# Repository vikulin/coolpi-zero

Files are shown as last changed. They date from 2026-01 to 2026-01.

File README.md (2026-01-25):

# GammaPi Zero - The portable FPGA development board



## What is the GammaPi Zero?

The GammaPi Zero is an FPGA development board in the popular Raspberry Pi Zero form factor inheriting Icepi Zero board. It carries a Lattice ECP5 25F, enabling powerful designs while keeping a small portable size. It also has a GPDI mini (General Purpose Display Interface, same as the one on the Pi Zero) port allowing easy digital video output.



## Why GammaPi Zero?

Currently most powerful FPGA boards on the market are expensive and bulky.

I've always wanted a low-cost portable FPGA with video output to make my own CPU, but there isn't any on the market.

The GammaPi Zero aims to fix this. Carrying a powerful ECP5 FPGA on a small Raspberry Pi Zero form factor, it is the ultimate portable solution for FPGA development. Additionally packing a GPDI mini port and 3 USB-C ports, it allows interfacing with multiple external I/O devGammas.

GammaPi Zero is for everyone: Students can use it to learn about the internals of modern processors. Gamers can use it to emulate old hardware. Programmers can use it to test their code on multiple architectures.


<sub>Oberon running on GammaPi Zero</sub>

GammaPi Zero also has an on-board USB to JTAG converter, so no external programmers are needed.

Moreover GammaPi Zero is fully open-source, no strings attached. Learn from the design! ([OSHWA cerified FR000026](https://certification.oshwa.org/fr000026.html)).



## Features
    * Lattice ECP5U-25F-CABGA256 FPGA
    * 256 Mib SDRAM
    * DVI video output via HDMI connector
    * 25 MBPS ADC
    * 3× USB ports (1× programming/JTAG, 2× general purpose)
    * USB-JTAG programming interface
    * Mini SD card reader
    * 5× RGB LEDs
    * 2× user buttons
    * RP Zero–compatible pins and board size
    * Board dimensions: 65 × 30 mm

This powerful configuration allows the PCB to be used in numerous ways, including real time video processing, hardware AI acceleration and prototyping of ASICs. 

## Emulation

Over the course of multiple weeks, multiple emulation cores have been ported over, such as the [Oberon](https://github.com/cheyao/oberon), [Apple I](https://github.com/cheyao/apple-one) and the [Acorn Atom](https://github.com/cheyao/acorn_atom)! The GammaPi Zero allows you to take cycle accurate replicas of your favourite systems in your pocket.


<sub>Apple I running on the GammaPi</sub>


<sub>Acorn Atom running on the GammaPi</sub>

## Learning

It is also supported by Icestudio (custom fork: https://github.com/cheyao/Icestudio), allowing easy access for beginners.



## Usage

Check out the `firmware` folder for example code and compilation instructions!

If you want to order this board, it uses a 1.2mm/1.6mm PCB with JLC04121H-7628 Stackup. Gerbers are in the `production` folder in the `hardware` directory.

For the PCB, the smallest component size is 0201 for 27 Ohm resistors on the USB-C datalines. But if you want only 0402 components, just delete those 0201 resistors and you will be fine.

NOTE: If you fabbed v1.1 before 01/06, the pins of the USB pullups and LED0 is different - check your gerbers.



## Contact

If there is any questions email me `vadym.vikulin _at_ gmail.com` or DM `@Cyao` on Hackclub Slack.

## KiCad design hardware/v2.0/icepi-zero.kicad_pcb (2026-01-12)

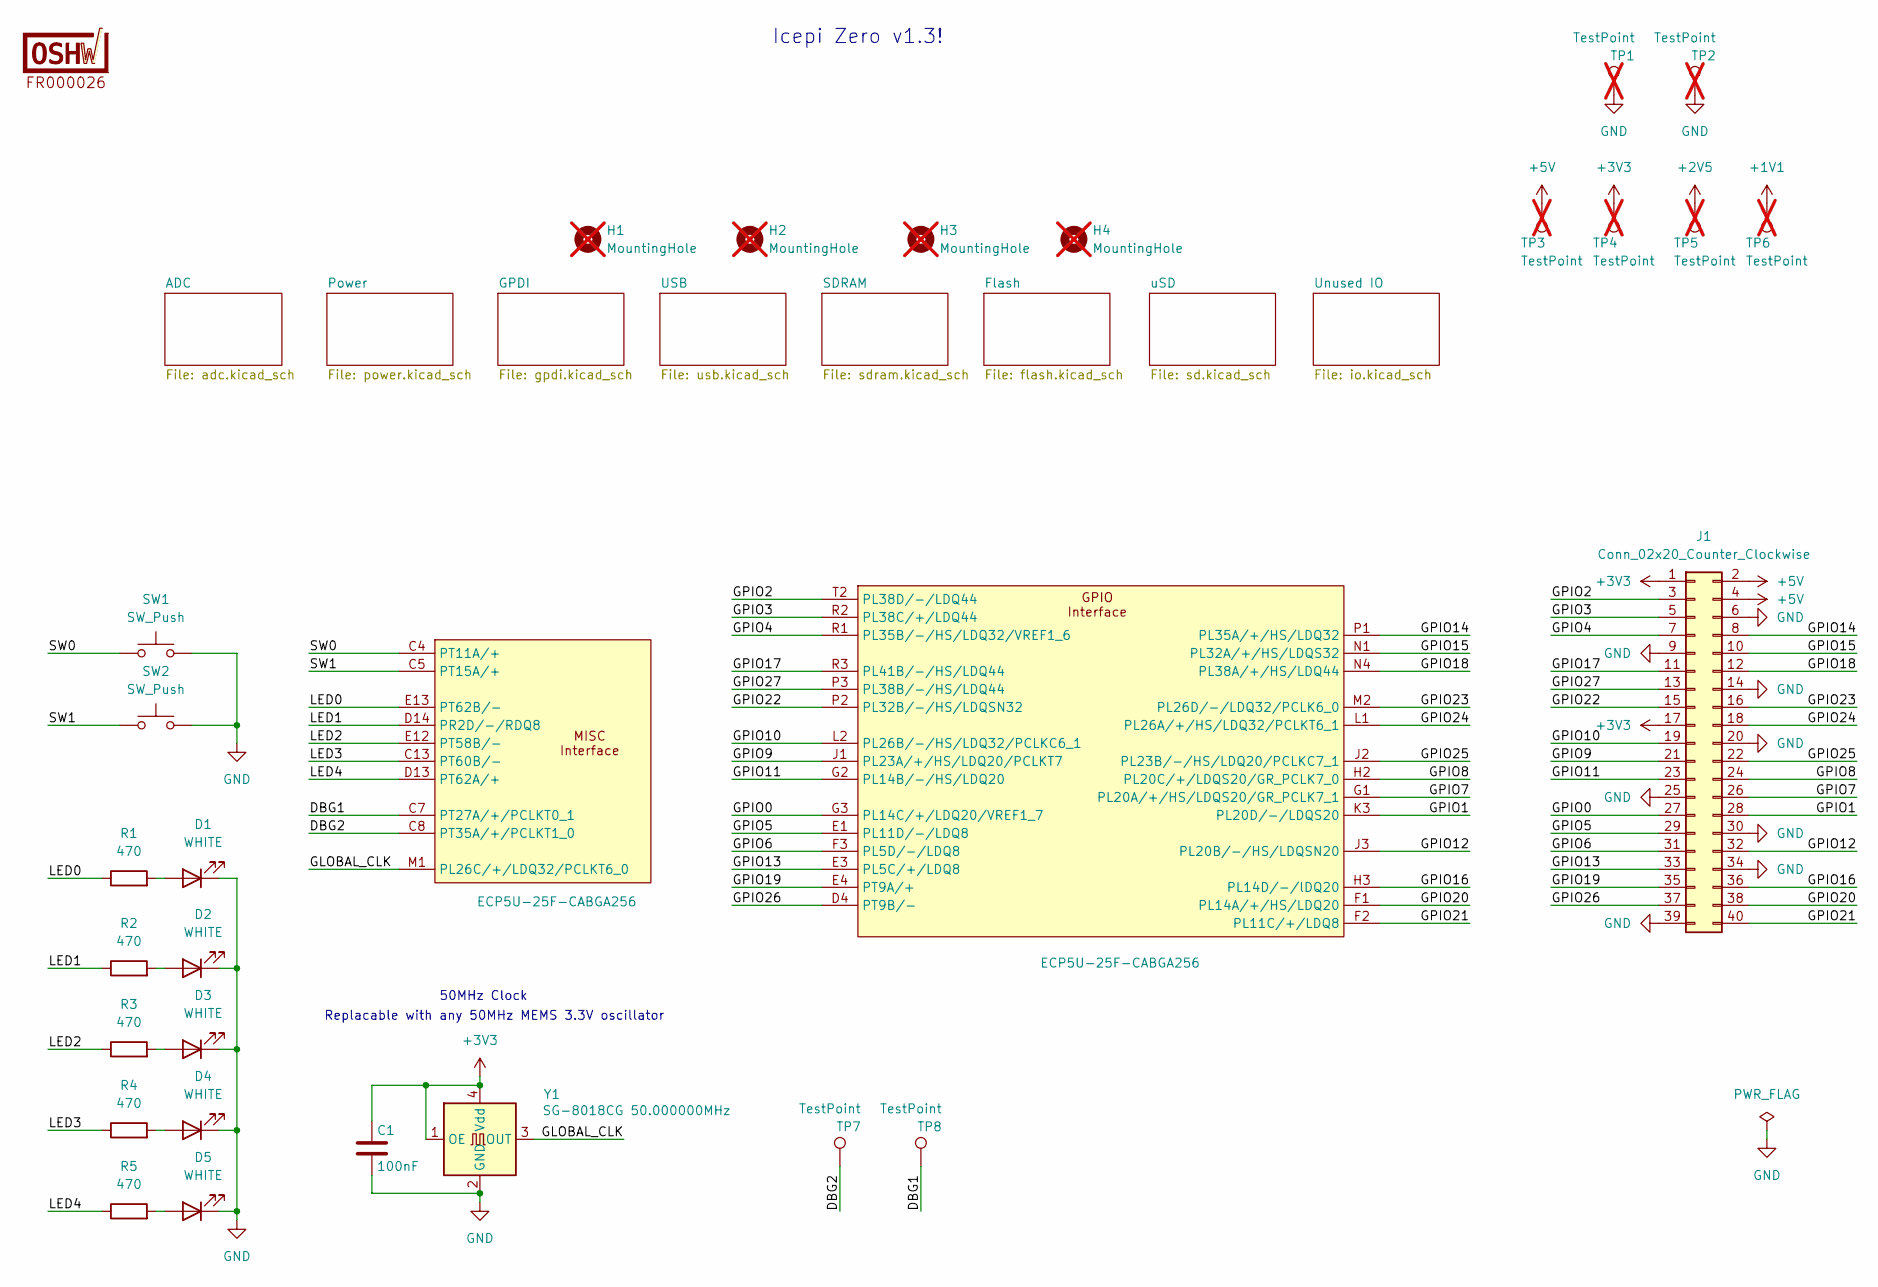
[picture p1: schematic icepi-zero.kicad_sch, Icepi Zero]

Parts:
C1: 100nF; C_0402_1005Metric; Manufactuer Part Number CL05B104KB54PNC; LCSC Part # C307331
D1, D2, D3, D4, D5: WHITE; LED_0603_1608Metric; Manufactuer Part Number KT-0603W; LCSC Part # C2290
H1, H2, H3, H4: MountingHole; MountingHole_2.7mm_M2.5; not fitted
J1: Conn_02x20_Counter_Clockwise; PinHeader_2x20_P2.54mm_Vertical
LOGO1: OSHW-Certification-Mark-Logo_6x3mm_SilkScreen
R1, R2, R3, R4, R5: 470; R_0402_1005Metric; Manufactuer Part Number 0402WGF4700TCE; LCSC Part # C25117
SW1, SW2: SW_Push; switch_button_TS-1088-AR02016; Manufactuer Part Number TS-1088-AR02016; LCSC Part # C720477
TP1, TP2, TP3, TP4, TP5, TP6: TestPoint; TestPoint_Pad_D2.0mm_Blank; not fitted
TP7, TP8: TestPoint; TestPoint_Pad_D1.0mm_Blank
U1: ECP5U-25F-CABGA256; BGA-256_14.0x14.0mm_Layout16x16_P0.8mm_Ball0.45mm_Pad0.32mm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
Y1: SG-8018CG 50.000000MHz; Oscillator_SMD_SiT_PQFN-4Pin_2.5x2.0mm; Manufactuer Part Number SG-8018CG 50.000000MHz TJHSA; LCSC Part # C390526

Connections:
+1V1: TP6.1; also elsewhere on the board
+2V5: TP5.1; also elsewhere on the board
+3V3: C1.1, J1.1, J1.17, TP4.1, Y1.1 (OE), Y1.4 (Vdd); also elsewhere on the board
+5V: J1.2, J1.4, TP3.1; also elsewhere on the board
/DBG1: TP8.1, U1.C7 (PT27A/+/PCLKT0_1)
/DBG2: TP7.1, U1.C8 (PT35A/+/PCLKT1_0)
/GLOBAL_CLK: U1.M1 (PL26C/+/LDQ32/PCLKT6_0), Y1.3 (OUT)
/GPIO0: J1.27, U1.G3 (PL14C/+/LDQ20/VREF1_7)
/GPIO1: J1.28, U1.K3 (PL20D/-/LDQS20)
/GPIO2: J1.3, U1.T2 (PL38D/-/LDQ44)
/GPIO3: J1.5, U1.R2 (PL38C/+/LDQ44)
/GPIO4: J1.7, U1.R1 (PL35B/-/HS/LDQ32/VREF1_6)
/GPIO5: J1.29, U1.E1 (PL11D/-/LDQ8)
/GPIO6: J1.31, U1.F3 (PL5D/-/LDQ8)
/GPIO7: J1.26, U1.G1 (PL20A/+/HS/LDQS20/GR_PCLK7_1)
/GPIO8: J1.24, U1.H2 (PL20C/+/LDQS20/GR_PCLK7_0)
/GPIO9: J1.21, U1.J1 (PL23A/+/HS/LDQ20/PCLKT7)
/GPIO10: J1.19, U1.L2 (PL26B/-/HS/LDQ32/PCLKC6_1)
/GPIO11: J1.23, U1.G2 (PL14B/-/HS/LDQ20)
/GPIO12: J1.32, U1.J3 (PL20B/-/HS/LDQSN20)
/GPIO13: J1.33, U1.E3 (PL5C/+/LDQ8)
/GPIO14: J1.8, U1.P1 (PL35A/+/HS/LDQ32)
/GPIO15: J1.10, U1.N1 (PL32A/+/HS/LDQS32)
/GPIO16: J1.36, U1.H3 (PL14D/-/lDQ20)
/GPIO17: J1.11, U1.R3 (PL41B/-/HS/LDQ44)
/GPIO18: J1.12, U1.N4 (PL38A/+/HS/LDQ44)
/GPIO19: J1.35, U1.E4 (PT9A/+)
/GPIO20: J1.38, U1.F1 (PL14A/+/HS/LDQ20)
/GPIO21: J1.40, U1.F2 (PL11C/+/LDQ8)
/GPIO22: J1.15, U1.P2 (PL32B/-/HS/LDQSN32)
/GPIO23: J1.16, U1.M2 (PL26D/-/LDQ32/PCLK6_0)
/GPIO24: J1.18, U1.L1 (PL26A/+/HS/LDQ32/PCLKT6_1)
/GPIO25: J1.22, U1.J2 (PL23B/-/HS/LDQ20/PCLKC7_1)
/GPIO26: J1.37, U1.D4 (PT9B/-)
/GPIO27: J1.13, U1.P3 (PL38B/-/HS/LDQ44)
/LED0: R1.1, U1.E13 (PT62B/-)
/LED1: R2.1, U1.D14 (PR2D/-/RDQ8)
/LED2: R3.1, U1.E12 (PT58B/-)
/LED3: R4.1, U1.C13 (PT60B/-)
/LED4: R5.1, U1.D13 (PT62A/+)
/SW0: SW1.1, U1.C4 (PT11A/+)
/SW1: SW2.1, U1.C5 (PT15A/+)
GND: C1.2, D1.1 (K), D2.1 (K), D3.1 (K), D4.1 (K), D5.1 (K), J1.6, J1.9, J1.14, J1.20, J1.25, J1.30, J1.34, J1.39, SW1.2, SW2.2, TP1.1, TP2.1, Y1.2 (GND); also elsewhere on the board
unnamed: D1.2 (A), R1.2
unnamed: D2.2 (A), R2.2
unnamed: D3.2 (A), R3.2
unnamed: D4.2 (A), R4.2
unnamed: D5.2 (A), R5.2

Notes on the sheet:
Icepi Zero v1.3!
Replacable with any 50MHz MEMS 3.3V oscillator
50MHz Clock

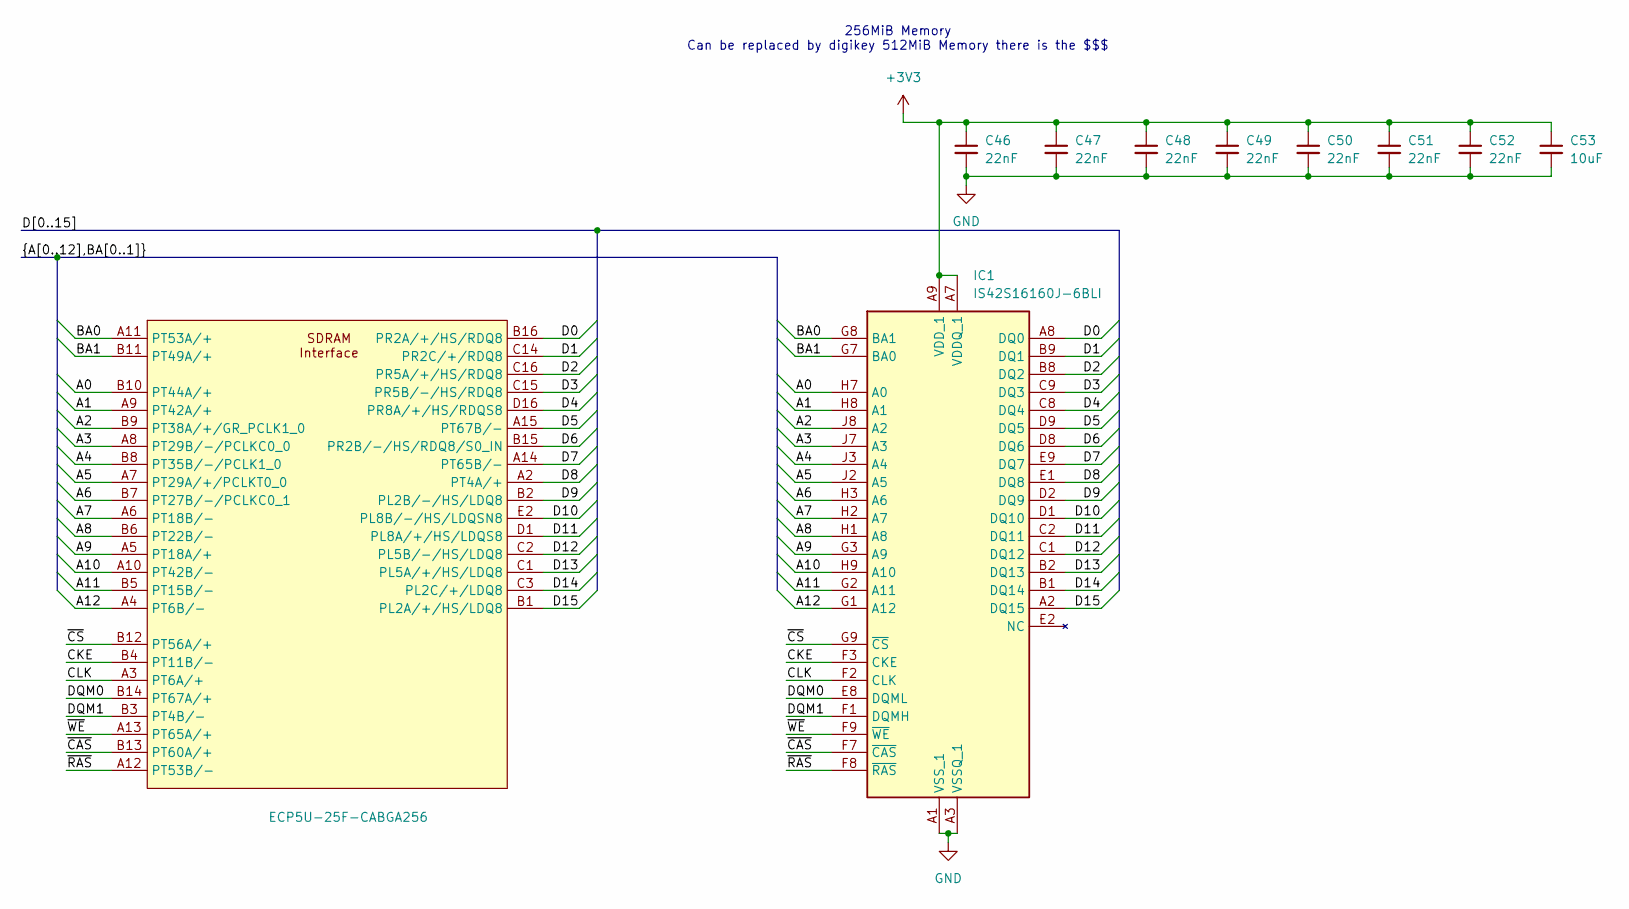
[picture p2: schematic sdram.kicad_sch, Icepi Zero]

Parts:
C46, C47, C48, C49, C50, C51, C52: 22nF; C_0603_1608Metric; Manufactuer Part Number 0603B223K500NT; LCSC Part # C77571
C53: 10uF; C_0603_1608Metric; Manufactuer Part Number CL10A106KP8NNNC; LCSC Part # C19702
IC1: IS42S16160J-6BLI; BGA54C80P9X9_800X800X120; Mouser Part Number 870-42S16160J6BLI
U1: ECP5U-25F-CABGA256; BGA-256_14.0x14.0mm_Layout16x16_P0.8mm_Ball0.45mm_Pad0.32mm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

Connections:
+3V3: C46.1, C47.1, C48.1, C49.1, C50.1, C51.1, C52.1, C53.1, IC1.A7 (VDDQ_1), IC1.A9 (VDD_1), IC1.B3 (VDDQ_2), IC1.C7 (VDDQ_3), IC1.D3 (VDDQ_4), IC1.E7 (VDD_2), IC1.J9 (VDD_3); also elsewhere on the board
/SDRAM/A0: IC1.H7 (A0), U1.B10 (PT44A/+)
/SDRAM/A1: IC1.H8 (A1), U1.A9 (PT42A/+)
/SDRAM/A2: IC1.J8 (A2), U1.B9 (PT38A/+/GR_PCLK1_0)
/SDRAM/A3: IC1.J7 (A3), U1.A8 (PT29B/-/PCLKC0_0)
/SDRAM/A4: IC1.J3 (A4), U1.B8 (PT35B/-/PCLK1_0)
/SDRAM/A5: IC1.J2 (A5), U1.A7 (PT29A/+/PCLKT0_0)
/SDRAM/A6: IC1.H3 (A6), U1.B7 (PT27B/-/PCLKC0_1)
/SDRAM/A7: IC1.H2 (A7), U1.A6 (PT18B/-)
/SDRAM/A8: IC1.H1 (A8), U1.B6 (PT22B/-)
/SDRAM/A9: IC1.G3 (A9), U1.A5 (PT18A/+)
/SDRAM/A10: IC1.H9 (A10), U1.A10 (PT42B/-)
/SDRAM/A11: IC1.G2 (A11), U1.B5 (PT15B/-)
/SDRAM/A12: IC1.G1 (A12), U1.A4 (PT6B/-)
/SDRAM/BA0: IC1.G8 (BA1), U1.A11 (PT53A/+)
/SDRAM/BA1: IC1.G7 (BA0), U1.B11 (PT49A/+)
/SDRAM/CKE: IC1.F3 (CKE), U1.B4 (PT11B/-)
/SDRAM/CLK: IC1.F2 (CLK), U1.A3 (PT6A/+)
/SDRAM/D0: IC1.A8 (DQ0), U1.B16 (PR2A/+/HS/RDQ8)
/SDRAM/D1: IC1.B9 (DQ1), U1.C14 (PR2C/+/RDQ8)
/SDRAM/D2: IC1.B8 (DQ2), U1.C16 (PR5A/+/HS/RDQ8)
/SDRAM/D3: IC1.C9 (DQ3), U1.C15 (PR5B/-/HS/RDQ8)
/SDRAM/D4: IC1.C8 (DQ4), U1.D16 (PR8A/+/HS/RDQS8)
/SDRAM/D5: IC1.D9 (DQ5), U1.A15 (PT67B/-)
/SDRAM/D6: IC1.D8 (DQ6), U1.B15 (PR2B/-/HS/RDQ8/S0_IN)
/SDRAM/D7: IC1.E9 (DQ7), U1.A14 (PT65B/-)
/SDRAM/D8: IC1.E1 (DQ8), U1.A2 (PT4A/+)
/SDRAM/D9: IC1.D2 (DQ9), U1.B2 (PL2B/-/HS/LDQ8)
/SDRAM/D10: IC1.D1 (DQ10), U1.E2 (PL8B/-/HS/LDQSN8)
/SDRAM/D11: IC1.C2 (DQ11), U1.D1 (PL8A/+/HS/LDQS8)
/SDRAM/D12: IC1.C1 (DQ12), U1.C2 (PL5B/-/HS/LDQ8)
/SDRAM/D13: IC1.B2 (DQ13), U1.C1 (PL5A/+/HS/LDQ8)
/SDRAM/D14: IC1.B1 (DQ14), U1.C3 (PL2C/+/LDQ8)
/SDRAM/D15: IC1.A2 (DQ15), U1.B1 (PL2A/+/HS/LDQ8)
/SDRAM/DQM0: IC1.E8 (DQML), U1.B14 (PT67A/+)
/SDRAM/DQM1: IC1.F1 (DQMH), U1.B3 (PT4B/-)
/SDRAM/~CAS: IC1.F7 (~CAS), U1.B13 (PT60A/+)
/SDRAM/~CS: IC1.G9 (~CS), U1.B12 (PT56A/+)
/SDRAM/~RAS: IC1.F8 (~RAS), U1.A12 (PT53B/-)
/SDRAM/~WE: IC1.F9 (~WE), U1.A13 (PT65A/+)
GND: C46.2, C47.2, C48.2, C49.2, C50.2, C51.2, C52.2, C53.2, IC1.A1 (VSS_1), IC1.A3 (VSSQ_1), IC1.B7 (VSSQ_2), IC1.C3 (VSSQ_3), IC1.D7 (VSSQ_4), IC1.E3 (VSS_2), IC1.J1 (VSS_3); also elsewhere on the board

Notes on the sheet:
256MiB Memory Can be replaced by digikey 512MiB Memory there is the $$$

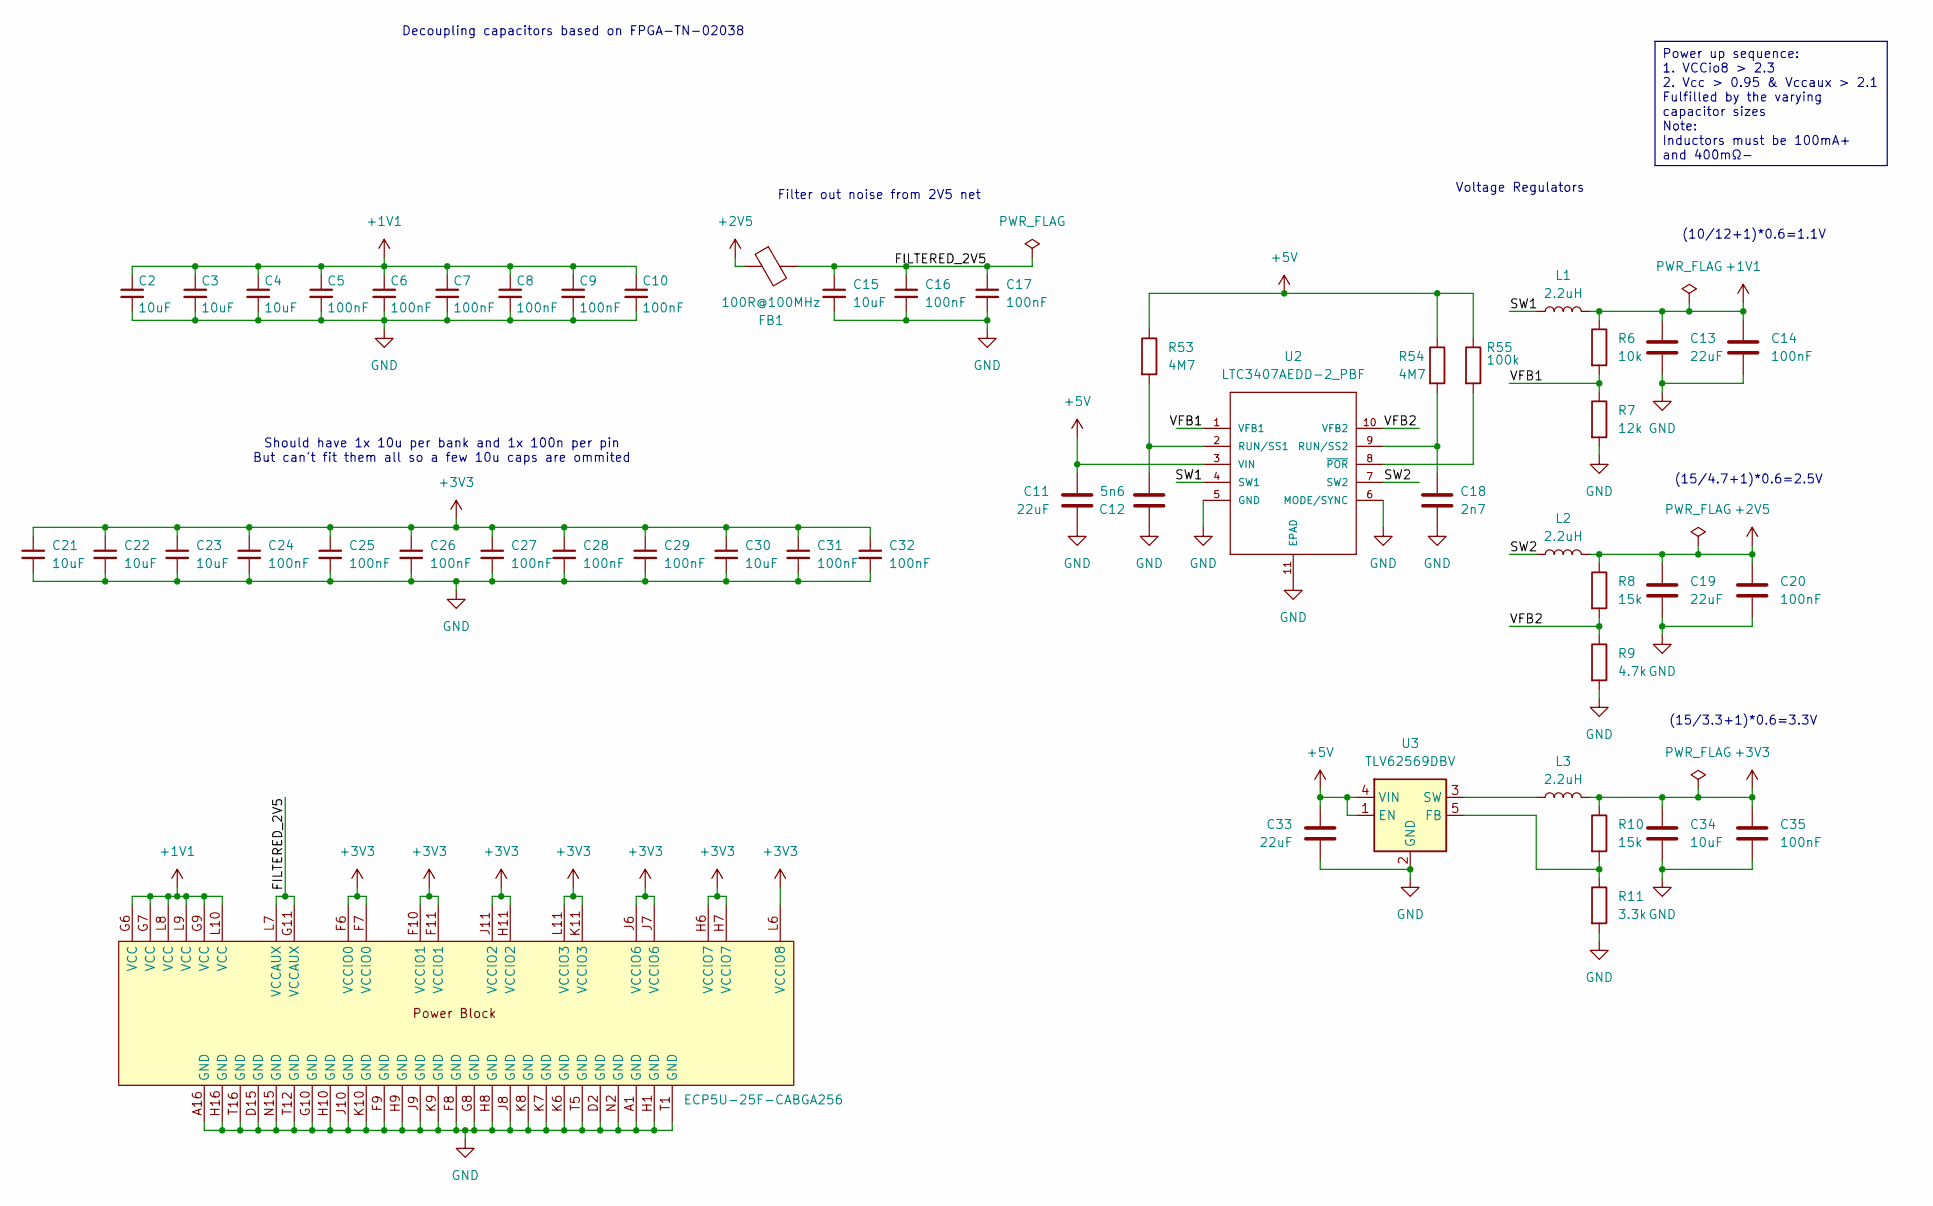
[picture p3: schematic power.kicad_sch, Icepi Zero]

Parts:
C2, C3, C4, C15, C21, C22, C23, C30, C34: 10uF; C_0603_1608Metric; Manufactuer Part Number CL10A106KP8NNNC; LCSC Part # C19702
C5, C6, C7, C8, C9, C10, C14, C16, C17, C20, C24, C25, C26, C27, C28, C29, C31, C32, C35: 100nF; C_0402_1005Metric; Manufactuer Part Number CL05B104KB54PNC; LCSC Part # C307331
C11, C13, C19, C33: 22uF; C_0603_1608Metric; Manufactuer Part Number CL10A226MQ8NRNC; LCSC Part # C59461
C12: 5n6; C_0402_1005Metric; Manufactuer Part Number CL05B562KB5NNNC; LCSC Part # C307435
C18: 2n7; C_0402_1005Metric; Manufactuer Part Number CL05B272KB5NNNC; LCSC Part # C84704
FB1: 100R@100MHz; L_0805_2012Metric; Manufactuer Part Number CBG201209U101T; LCSC Part # C74480
L1, L2, L3: 2.2uH; L_0805_2012Metric; Manufactuer Part Number TDK MLP2012S2R2MT0S1; LCSC Part # C107322
R6: 10k; R_0402_1005Metric; Manufactuer Part Number 0402WGF1002TCE; LCSC Part # C25744
R7: 12k; R_0402_1005Metric; Manufactuer Part Number 0402WGF1202TCE; LCSC Part # C25752
R8, R10: 15k; R_0402_1005Metric; Manufactuer Part Number 0402WGF1502TCE; LCSC Part # C25756
R9: 4.7k; R_0402_1005Metric; Manufactuer Part Number 0402WGF4701TCE; LCSC Part # C25900
R11: 3.3k; R_0402_1005Metric; Manufactuer Part Number 0402WGF3301TCE; LCSC Part # C25890
R53, R54: 4M7; R_0402_1005Metric; Manufactuer Part Number 0402WGF4704TCE; LCSC Part # C474132
R55: 100k; R_0402_1005Metric; Manufactuer Part Number 0402WGF1003TCE; LCSC Part # C25744
U1: ECP5U-25F-CABGA256; BGA-256_14.0x14.0mm_Layout16x16_P0.8mm_Ball0.45mm_Pad0.32mm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
U2: LTC3407AEDD-2_PBF; DFN-10_DD; MANUFACTURER_PART_NUMBER ltc3407aedd2
U3: TLV62569DBV; SOT-23-5; Manufactuer Part Number TLV62569DBVR; LCSC Part # C141836

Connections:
+1V1: C2.1, C3.1, C4.1, C5.1, C6.1, C7.1, C8.1, C9.1, C10.1, C13.1, C14.1, L1.2, R6.1, U1.G6 (VCC), U1.G7 (VCC), U1.G9 (VCC), U1.L8 (VCC), U1.L9 (VCC), U1.L10 (VCC); also elsewhere on the board
+2V5: C19.1, C20.1, FB1.1, L2.2, R8.1; also elsewhere on the board
+3V3: C21.1, C22.1, C23.1, C24.1, C25.1, C26.1, C27.1, C28.1, C29.1, C30.1, C31.1, C32.1, C34.1, C35.1, L3.2, R10.1, U1.F6 (VCCIO0), U1.F7 (VCCIO0), U1.F10 (VCCIO1), U1.F11 (VCCIO1), U1.H6 (VCCIO7), U1.H7 (VCCIO7), U1.H11 (VCCIO2), U1.J6 (VCCIO6), U1.J7 (VCCIO6), U1.J11 (VCCIO2), U1.K11 (VCCIO3), U1.L6 (VCCIO8), U1.L11 (VCCIO3); also elsewhere on the board
+5V: C11.1, C33.1, R53.1, R54.1, R55.1, U2.3 (VIN), U3.1 (EN), U3.4 (VIN); also elsewhere on the board
/Power/FILTERED_2V5: C15.1, C16.1, C17.1, FB1.2, U1.G11 (VCCAUX), U1.L7 (VCCAUX)
/Power/SW1: L1.1, U2.4 (SW1)
/Power/SW2: L2.1, U2.7 (SW2)
/Power/VFB1: R6.2, R7.1, U2.1 (VFB1)
/Power/VFB2: R8.2, R9.1, U2.10 (VFB2)
GND: C2.2, C3.2, C4.2, C5.2, C6.2, C7.2, C8.2, C9.2, C10.2, C11.2, C12.1, C13.2, C14.2, C15.2, C16.2, C17.2, C18.2, C19.2, C20.2, C21.2, C22.2, C23.2, C24.2, C25.2, C26.2, C27.2, C28.2, C29.2, C30.2, C31.2, C32.2, C33.2, C34.2, C35.2, R7.2, R9.2, R11.2, U1.A1 (GND), U1.A16 (GND), U1.D2 (GND), U1.D15 (GND), U1.F8 (GND), U1.F9 (GND), U1.G8 (GND), U1.G10 (GND), U1.H1 (GND), U1.H8 (GND), U1.H9 (GND), U1.H10 (GND), U1.H16 (GND), U1.J8 (GND), U1.J9 (GND), U1.J10 (GND), U1.K6 (GND), U1.K7 (GND), U1.K8 (GND), U1.K9 (GND), U1.K10 (GND), U1.N2 (GND), U1.N15 (GND), U1.T1 (GND), U1.T5 (GND), U1.T12 (GND), U1.T16 (GND), U2.5 (GND), U2.6 (MODE/SYNC), U2.11 (EPAD), U3.2 (GND); also elsewhere on the board
unnamed: C12.2, R53.2, U2.2 (RUN/SS1)
unnamed: C18.1, R54.2, U2.9 (RUN/SS2)
unnamed: R55.2, U2.8 (~POR)
unnamed: R10.2, R11.1, U3.5 (FB)
unnamed: L3.1, U3.3 (SW)

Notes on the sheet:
Decoupling capacitors based on FPGA-TN-02038
(15/4.7+1)*0.6=2.5V
(10/12+1)*0.6=1.1V
Filter out noise from 2V5 net
(15/3.3+1)*0.6=3.3V
Should have 1x 10u per bank and 1x 100n per pin But can't fit them all so a few 10u caps are ommited
Voltage Regulators
Power up sequence: 1. VCCio8 > 2.3 2. Vcc > 0.95 & Vccaux > 2.1 Fulfilled by the varying capacitor sizes Note: Inductors must be 100mA+ and 400mΩ-

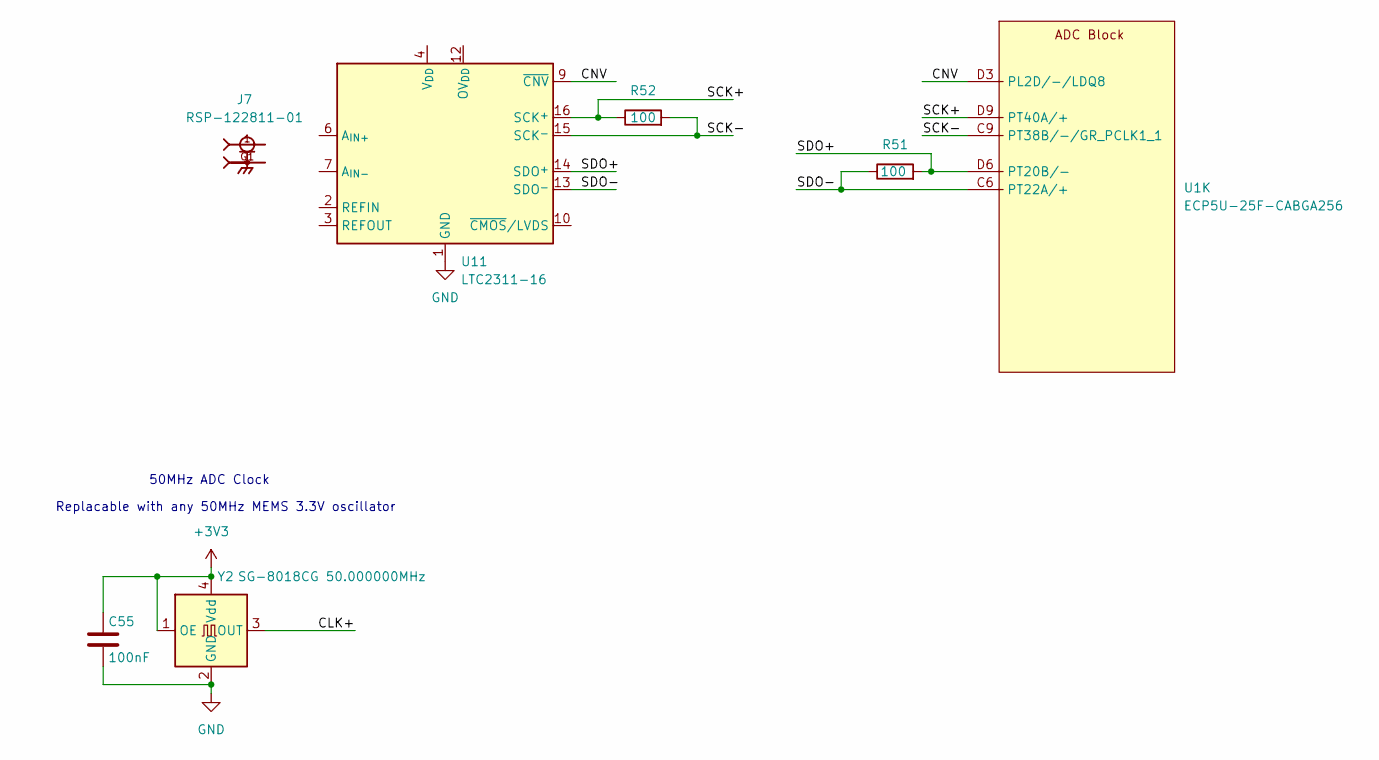
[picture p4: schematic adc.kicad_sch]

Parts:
C55: 100nF; C_0402_1005Metric; Manufactuer Part Number CL05B104KB54PNC; LCSC Part # C307331
J7: RSP-122811-01; SAMTEC_RSP-122811-01; PARTREV H
R51, R52: 100; R_0402_1005Metric; Manufactuer Part Number 0402WGF1000TCE; LCSC Part # C25076
U1: ECP5U-25F-CABGA256; BGA-256_14.0x14.0mm_Layout16x16_P0.8mm_Ball0.45mm_Pad0.32mm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
U11: LTC2311-16; MSOP-16-1EP_3x4.039mm_P0.5mm_EP1.651x2.845mm
Y2: SG-8018CG 50.000000MHz; Oscillator_SMD_SiT_PQFN-4Pin_2.5x2.0mm; Manufactuer Part Number SG-8018CG 50.000000MHz TJHSA; LCSC Part # C390526

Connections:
+3V3: C55.1, Y2.1 (OE), Y2.4 (Vdd); also elsewhere on the board
/ADC/CLK+: Y2.3 (OUT)
/ADC/CNV: U1.D3 (PL2D/-/LDQ8), U11.9 (~CNV)
/ADC/SCK+: R52.1, U1.D9 (PT40A/+), U11.16 (SCK^{+})
/ADC/SCK-: R52.2, U1.C9 (PT38B/-/GR_PCLK1_1), U11.15 (SCK^{-})
/ADC/SDO+: R51.2, U1.D6 (PT20B/-), U11.14 (SDO^{+})
/ADC/SDO-: R51.1, U1.C6 (PT22A/+), U11.13 (SDO^{-})
GND: C55.2, U11.1 (GND), U11.5 (GND), U11.8 (GND), U11.11 (GND), U11.17 (GND), Y2.2 (GND); also elsewhere on the board
unnamed: J7.G1, J7.G2

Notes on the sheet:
50MHz ADC Clock
Replacable with any 50MHz MEMS 3.3V oscillator

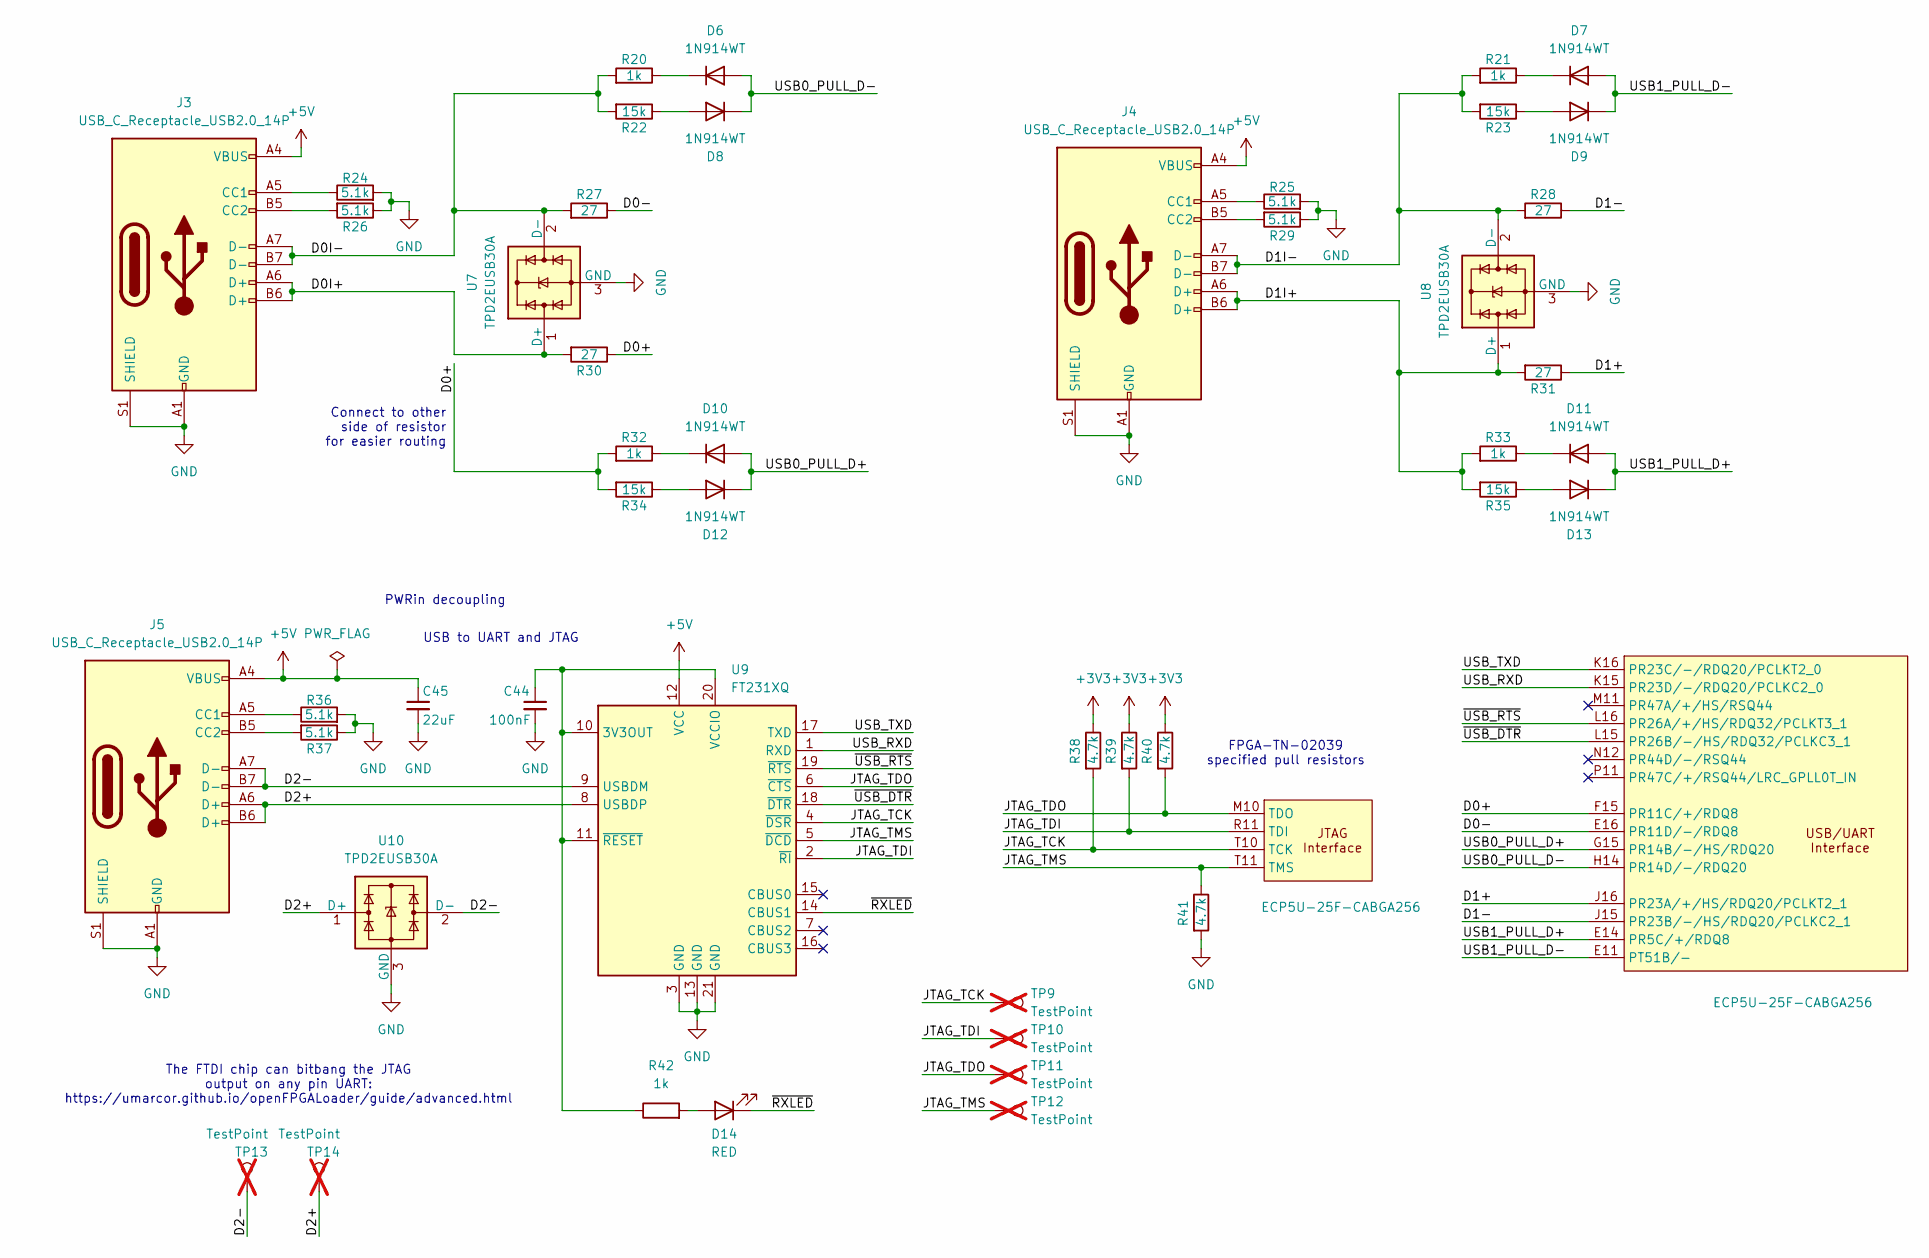
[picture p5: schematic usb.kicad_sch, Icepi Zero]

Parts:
C44: 100nF; C_0402_1005Metric; Manufactuer Part Number CL05B104KB54PNC; LCSC Part # C307331
C45: 22uF; C_0603_1608Metric; Manufactuer Part Number CL10A226MQ8NRNC; LCSC Part # C59461
D6, D7, D8, D9, D10, D11, D12, D13: 1N914WT; D_SOD-523; Manufactuer Part Number 1N914WT; LCSC Part # C2836064
D14: RED; LED_0603_1608Metric; Manufactuer Part Number KT-0603R; LCSC Part # C2286
J3, J4, J5: USB_C_Receptacle_USB2.0_14P; USB_C_Receptacle_GCT_USB4105-xx-A_16P_TopMnt_Horizontal; Manufactuer Part Number TYPE-C 16PIN 2MD(073); LCSC Part # C2765186
R20, R21, R32, R33, R42: 1k; R_0402_1005Metric; Manufactuer Part Number 0402WGF1001TCE; LCSC Part # C11702
R22, R23, R34, R35: 15k; R_0402_1005Metric; Manufactuer Part Number 0402WGF1502TCE; LCSC Part # C25756
R24, R25, R26, R29, R36, R37: 5.1k; R_0402_1005Metric; Manufactuer Part Number 0402WGF5101TCE; LCSC Part # C25905
R27, R28, R30, R31: 27; R_0201_0603Metric; Manufactuer Part Number 0201WMF270JTEE; LCSC Part # C473051
R38, R39, R40, R41: 4.7k; R_0402_1005Metric; Manufactuer Part Number 0402WGF4701TCE; LCSC Part # C25900
TP9, TP10, TP11, TP12: TestPoint; TestPoint_Pad_D1.0mm_Blank; not fitted
TP13, TP14: TestPoint; TestPoint_Pad_D2.0mm_Blank; not fitted
U1: ECP5U-25F-CABGA256; BGA-256_14.0x14.0mm_Layout16x16_P0.8mm_Ball0.45mm_Pad0.32mm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
U7, U8, U10: TPD2EUSB30A; Texas_DRT-3; Manufactuer Part Number TPD2EUSB30ADRTR; LCSC Part # C3011197
U9: FT231XQ; QFN-20-1EP_4x4mm_P0.5mm_EP2.5x2.5mm; Manufactuer Part Number FT231XQ-R; LCSC Part # C132159

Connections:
+3V3: R38.1, R39.1, R40.1; also elsewhere on the board
+5V: C45.1, J3.A4 (VBUS), J3.A9 (VBUS), J3.B4 (VBUS), J3.B9 (VBUS), J4.A4 (VBUS), J4.A9 (VBUS), J4.B4 (VBUS), J4.B9 (VBUS), J5.A4 (VBUS), J5.A9 (VBUS), J5.B4 (VBUS), J5.B9 (VBUS), U9.12 (VCC); also elsewhere on the board
/USB/D0+: R30.1, R32.2, R34.2, U1.F15 (PR11C/+/RDQ8)
/USB/D0-: R27.1, U1.E16 (PR11D/-/RDQ8)
/USB/D0I+: J3.A6 (D+), J3.B6 (D+), R30.2, U7.1 (D+)
/USB/D0I-: J3.A7 (D-), J3.B7 (D-), R20.2, R22.2, R27.2, U7.2 (D-)
/USB/D1+: R31.1, U1.J16 (PR23A/+/HS/RDQ20/PCLKT2_1)
/USB/D1-: R28.1, U1.J15 (PR23B/-/HS/RDQ20/PCLKC2_1)
/USB/D1I+: J4.A6 (D+), J4.B6 (D+), R31.2, R33.2, R35.2, U8.1 (D+)
/USB/D1I-: J4.A7 (D-), J4.B7 (D-), R21.2, R23.2, R28.2, U8.2 (D-)
/USB/D2+: J5.A6 (D+), J5.B6 (D+), TP14.1, U9.8 (USBDP), U10.1 (D+)
/USB/D2-: J5.A7 (D-), J5.B7 (D-), TP13.1, U9.9 (USBDM), U10.2 (D-)
/USB/JTAG_TCK: R38.2, TP9.1, U1.T10 (TCK), U9.4 (~DSR)
/USB/JTAG_TDI: R39.2, TP10.1, U1.R11 (TDI), U9.2 (~RI)
/USB/JTAG_TDO: R40.2, TP11.1, U1.M10 (TDO), U9.6 (~CTS)
/USB/JTAG_TMS: R41.1, TP12.1, U1.T11 (TMS), U9.5 (~DCD)
/USB/USB0_PULL_D+: D10.2 (A), D12.1 (K), U1.G15 (PR14B/-/HS/RDQ20)
/USB/USB0_PULL_D-: D6.2 (A), D8.1 (K), U1.H14 (PR14D/-/RDQ20)
/USB/USB1_PULL_D+: D11.2 (A), D13.1 (K), U1.E14 (PR5C/+/RDQ8)
/USB/USB1_PULL_D-: D7.2 (A), D9.1 (K), U1.E11 (PT51B/-)
/USB/USB_RXD: U1.K15 (PR23D/-/RDQ20/PCLKC2_0), U9.1 (RXD)
/USB/USB_TXD: U1.K16 (PR23C/-/RDQ20/PCLKT2_0), U9.17 (TXD)
/USB/~RXLED: D14.1 (K), U9.14 (CBUS1)
/USB/~USB_DTR: U1.L15 (PR26B/-/HS/RDQ32/PCLKC3_1), U9.18 (~DTR)
/USB/~USB_RTS: U1.L16 (PR26A/+/HS/RDQ32/PCLKT3_1), U9.19 (~RTS)
GND: C44.2, C45.2, J3.A1 (GND), J3.A12 (GND), J3.B1 (GND), J3.B12 (GND), J3.S1 (SHIELD), J4.A1 (GND), J4.A12 (GND), J4.B1 (GND), J4.B12 (GND), J4.S1 (SHIELD), J5.A1 (GND), J5.A12 (GND), J5.B1 (GND), J5.B12 (GND), J5.S1 (SHIELD), R24.2, R25.2, R26.1, R29.1, R36.2, R37.1, R41.2, U7.3 (GND), U8.3 (GND), U9.3 (GND), U9.13 (GND), U9.21 (GND), U10.3 (GND); also elsewhere on the board
unnamed: D6.1 (K), R20.1
unnamed: D7.1 (K), R21.1
unnamed: D8.2 (A), R22.1
unnamed: D9.2 (A), R23.1
unnamed: D10.1 (K), R32.1
unnamed: D11.1 (K), R33.1
unnamed: D12.2 (A), R34.1
unnamed: D13.2 (A), R35.1
unnamed: D14.2 (A), R42.2
unnamed: J3.A5 (CC1), R24.1
unnamed: J3.B5 (CC2), R26.2
unnamed: J4.A5 (CC1), R25.1
unnamed: J4.B5 (CC2), R29.2
unnamed: J5.A5 (CC1), R36.1
unnamed: J5.B5 (CC2), R37.2
unnamed: C44.1, R42.1, U9.10 (3V3OUT), U9.11 (~RESET), U9.20 (VCCIO)

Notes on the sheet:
PWRin decoupling
FPGA-TN-02039 specified pull resistors
USB to UART and JTAG
The FTDI chip can bitbang the JTAG output on any pin UART: https://umarcor.github.io/openFPGALoader/guide/advanced.html
Connect to other side of resistor for easier routing

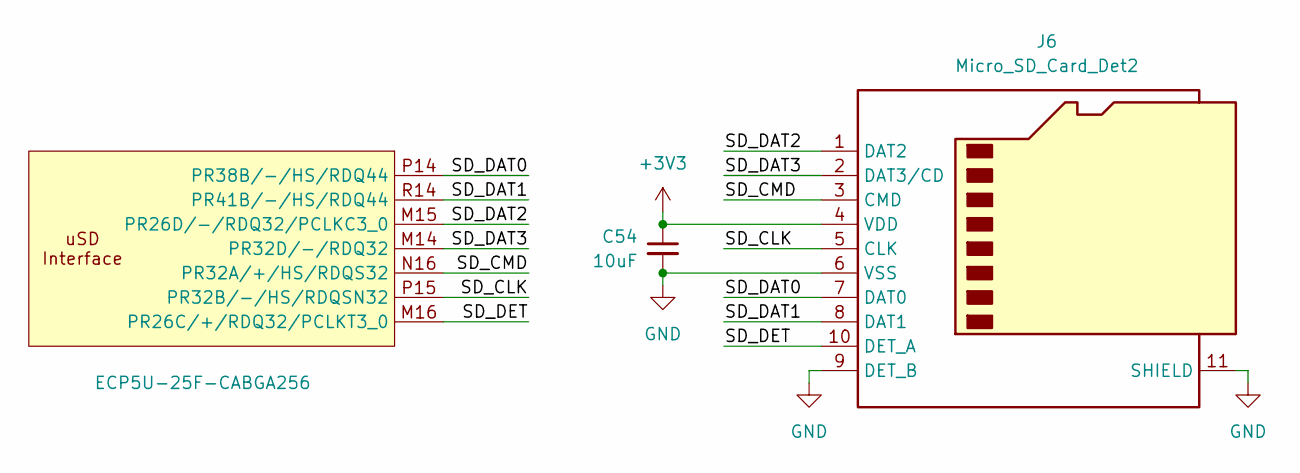
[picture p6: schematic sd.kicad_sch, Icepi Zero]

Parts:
C54: 10uF; C_0603_1608Metric; Manufactuer Part Number CL10A106KP8NNNC; LCSC Part # C19702
J6: Micro_SD_Card_Det2; microSD_HC_SOFNG_TF-008; Manufactuer Part Number TF-008; LCSC Part # C428465
U1: ECP5U-25F-CABGA256; BGA-256_14.0x14.0mm_Layout16x16_P0.8mm_Ball0.45mm_Pad0.32mm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

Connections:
+3V3: C54.1, J6.4 (VDD); also elsewhere on the board
/uSD/SD_CLK: J6.5 (CLK), U1.P15 (PR32B/-/HS/RDQSN32)
/uSD/SD_CMD: J6.3 (CMD), U1.N16 (PR32A/+/HS/RDQS32)
/uSD/SD_DAT0: J6.7 (DAT0), U1.P14 (PR38B/-/HS/RDQ44)
/uSD/SD_DAT1: J6.8 (DAT1), U1.R14 (PR41B/-/HS/RDQ44)
/uSD/SD_DAT2: J6.1 (DAT2), U1.M15 (PR26D/-/RDQ32/PCLKC3_0)
/uSD/SD_DAT3: J6.2 (DAT3/CD), U1.M14 (PR32D/-/RDQ32)
/uSD/SD_DET: J6.10 (DET_A), U1.M16 (PR26C/+/RDQ32/PCLKT3_0)
GND: C54.2, J6.6 (VSS), J6.9 (DET_B), J6.11 (SHIELD); also elsewhere on the board

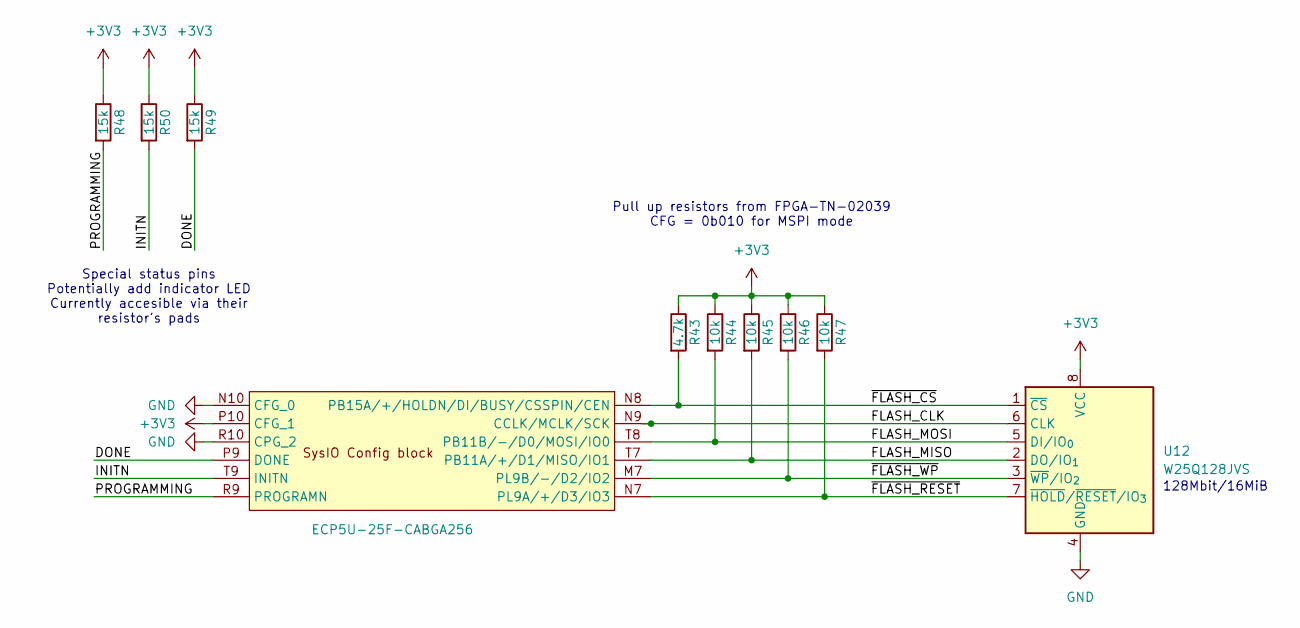
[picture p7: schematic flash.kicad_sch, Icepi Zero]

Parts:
R43: 4.7k; R_0402_1005Metric; Manufactuer Part Number 0402WGF4701TCE; LCSC Part # C25900
R44, R45, R46, R47: 10k; R_0402_1005Metric; Manufactuer Part Number 0402WGF1002TCE; LCSC Part # C25744
R48, R49, R50: 15k; R_0402_1005Metric; Manufactuer Part Number 0402WGF1502TCE; LCSC Part # C25756
U1: ECP5U-25F-CABGA256; BGA-256_14.0x14.0mm_Layout16x16_P0.8mm_Ball0.45mm_Pad0.32mm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
U12: W25Q128JVS; SOIC-8_5.3x5.3mm_P1.27mm; Manufactuer Part Number W25Q128JVSIQ; LCSC Part # C97521

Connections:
+3V3: R43.1, R44.1, R45.1, R46.1, R47.1, R48.1, R49.1, R50.1, U1.P10 (CFG_1), U12.8 (VCC); also elsewhere on the board
/Flash/DONE: R49.2, U1.P9 (DONE)
/Flash/FLASH_CLK: U1.N9 (CCLK/MCLK/SCK), U12.6 (CLK)
/Flash/FLASH_MISO: R45.2, U1.T7 (PB11A/+/D1/MISO/IO1), U12.2 (DO/IO_{1})
/Flash/FLASH_MOSI: R44.2, U1.T8 (PB11B/-/D0/MOSI/IO0), U12.5 (DI/IO_{0})
/Flash/INITN: R50.2, U1.T9 (INITN)
/Flash/PROGRAMMING: R48.2, U1.R9 (PROGRAMN)
/Flash/~FLASH_CS: R43.2, U1.N8 (PB15A/+/HOLDN/DI/BUSY/CSSPIN/CEN), U12.1 (~CS)
/Flash/~FLASH_RESET: R47.2, U1.N7 (PL9A/+/D3/IO3), U12.7 (~HOLD/~RESET/IO_{3})
/Flash/~FLASH_WP: R46.2, U1.M7 (PL9B/-/D2/IO2), U12.3 (~WP/IO_{2})
GND: U1.N10 (CFG_0), U1.R10 (CPG_2), U12.4 (GND); also elsewhere on the board

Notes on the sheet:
128Mbit/16MiB
Special status pins Potentially add indicator LED Currently accesible via their resistor's pads
Pull up resistors from FPGA-TN-02039 CFG = 0b010 for MSPI mode

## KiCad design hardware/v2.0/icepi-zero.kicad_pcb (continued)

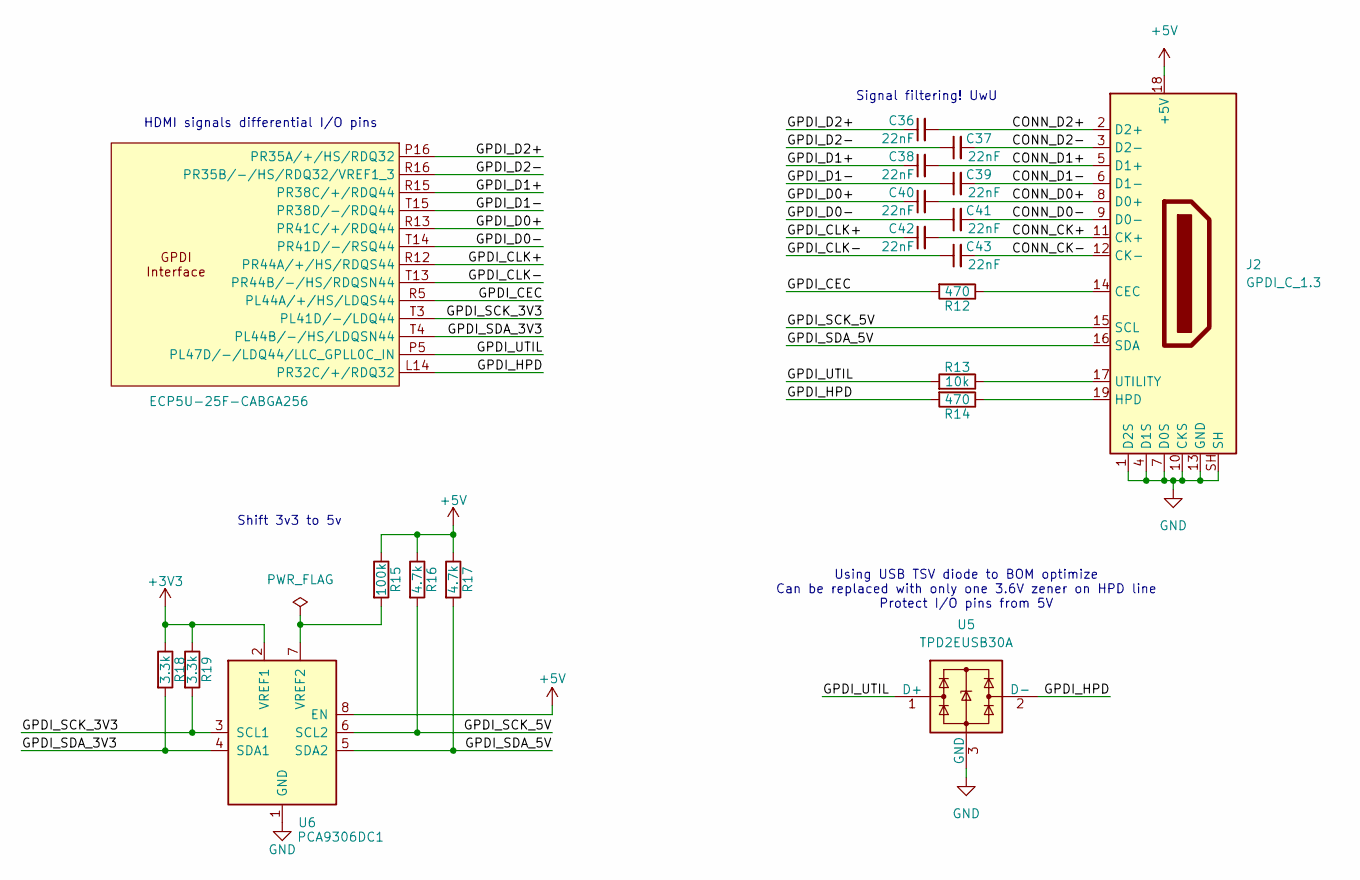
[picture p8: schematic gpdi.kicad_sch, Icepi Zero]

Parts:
C36, C37, C38, C39, C40, C41, C42, C43: 22nF; C_0402_1005Metric; Manufactuer Part Number 0402B223K500NT; LCSC Part # C1532
J2: GPDI_C_1.3; XKB Connection A71-05H4-111N1; Manufactuer Part Number A71-05H4-111N1; LCSC Part # C2682170
R12, R14: 470; R_0402_1005Metric; Manufactuer Part Number 0402WGF4700TCE; LCSC Part # C25117
R13: 10k; R_0402_1005Metric; Manufactuer Part Number 0402WGF1002TCE; LCSC Part # C25744
R15: 100k; R_0402_1005Metric; Manufactuer Part Number 0402WGF1003TCE; LCSC Part # C25741
R16, R17: 4.7k; R_0402_1005Metric; Manufactuer Part Number 0402WGF4701TCE; LCSC Part # C25900
R18, R19: 3.3k; R_0402_1005Metric; Manufactuer Part Number 0402WGF3301TCE; LCSC Part # C25890
U1: ECP5U-25F-CABGA256; BGA-256_14.0x14.0mm_Layout16x16_P0.8mm_Ball0.45mm_Pad0.32mm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
U5: TPD2EUSB30A; Texas_DRT-3; Manufactuer Part Number TPD2EUSB30ADRTR; LCSC Part # C3011197
U6: PCA9306DC1; VSSOP-8_2.3x2mm_P0.5mm; Manufactuer Part Number PCA9306DC1; LCSC Part # C129510

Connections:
+3V3: R18.1, R19.1, U6.2 (VREF1); also elsewhere on the board
+5V: J2.18 (+5V), R15.1, R16.1, R17.1, U6.8 (EN); also elsewhere on the board
/GPDI/CONN_CK+: C42.2, J2.11 (CK+)
/GPDI/CONN_CK-: C43.2, J2.12 (CK-)
/GPDI/CONN_D0+: C40.2, J2.8 (D0+)
/GPDI/CONN_D0-: C41.2, J2.9 (D0-)
/GPDI/CONN_D1+: C38.2, J2.5 (D1+)
/GPDI/CONN_D1-: C39.2, J2.6 (D1-)
/GPDI/CONN_D2+: C36.2, J2.2 (D2+)
/GPDI/CONN_D2-: C37.2, J2.3 (D2-)
/GPDI/GPDI_CEC: R12.2, U1.R5 (PL44A/+/HS/LDQS44)
/GPDI/GPDI_CLK+: C42.1, U1.R12 (PR44A/+/HS/RDQS44)
/GPDI/GPDI_CLK-: C43.1, U1.T13 (PR44B/-/HS/RDQSN44)
/GPDI/GPDI_D0+: C40.1, U1.R13 (PR41C/+/RDQ44)
/GPDI/GPDI_D0-: C41.1, U1.T14 (PR41D/-/RSQ44)
/GPDI/GPDI_D1+: C38.1, U1.R15 (PR38C/+/RDQ44)
/GPDI/GPDI_D1-: C39.1, U1.T15 (PR38D/-/RDQ44)
/GPDI/GPDI_D2+: C36.1, U1.P16 (PR35A/+/HS/RDQ32)
/GPDI/GPDI_D2-: C37.1, U1.R16 (PR35B/-/HS/RDQ32/VREF1_3)
/GPDI/GPDI_HPD: R14.2, U1.L14 (PR32C/+/RDQ32), U5.2 (D-)
/GPDI/GPDI_SCK_3V3: R19.2, U1.T3 (PL41D/-/LDQ44), U6.3 (SCL1)
/GPDI/GPDI_SCK_5V: J2.15 (SCL), R16.2, U6.6 (SCL2)
/GPDI/GPDI_SDA_3V3: R18.2, U1.T4 (PL44B/-/HS/LDQSN44), U6.4 (SDA1)
/GPDI/GPDI_SDA_5V: J2.16 (SDA), R17.2, U6.5 (SDA2)
/GPDI/GPDI_UTIL: R13.2, U1.P5 (PL47D/-/LDQ44/LLC_GPLL0C_IN), U5.1 (D+)
GND: J2.1 (D2S), J2.4 (D1S), J2.7 (D0S), J2.10 (CKS), J2.13 (GND), J2.SH, U5.3 (GND), U6.1 (GND); also elsewhere on the board
unnamed: J2.14 (CEC), R12.1
unnamed: J2.19 (HPD), R14.1
unnamed: J2.17 (UTILITY), R13.1
unnamed: R15.2, U6.7 (VREF2)

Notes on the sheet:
Shift 3v3 to 5v
Using USB TSV diode to BOM optimize Can be replaced with only one 3.6V zener on HPD line Protect I/O pins from 5V
HDMI signals differential I/O pins
Signal filtering! UwU

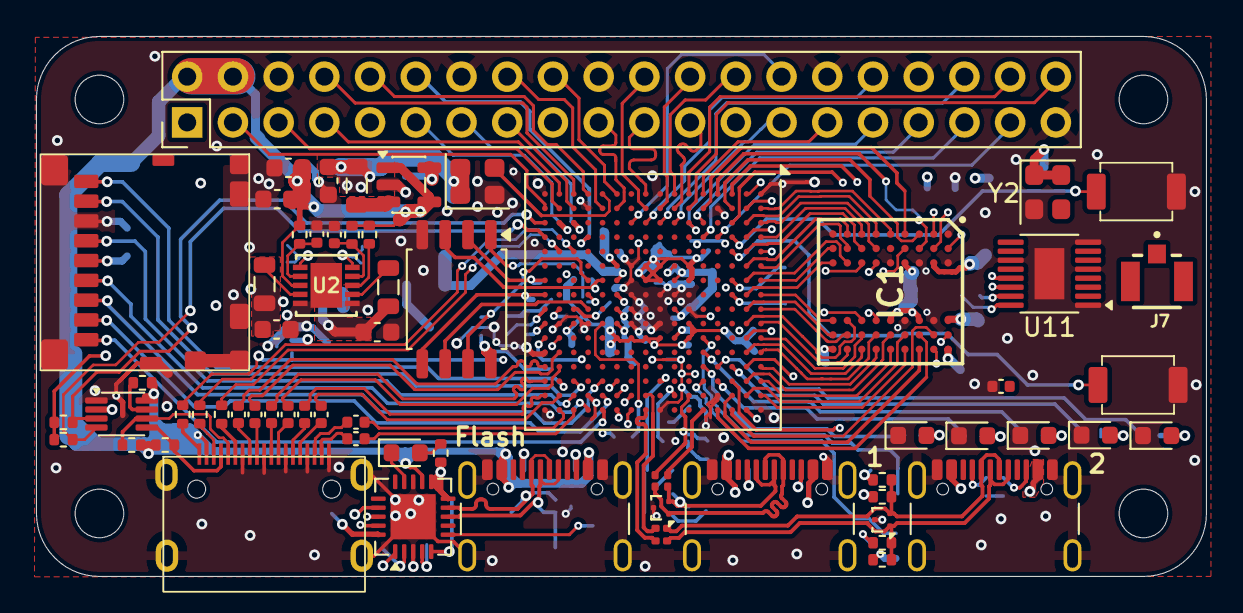
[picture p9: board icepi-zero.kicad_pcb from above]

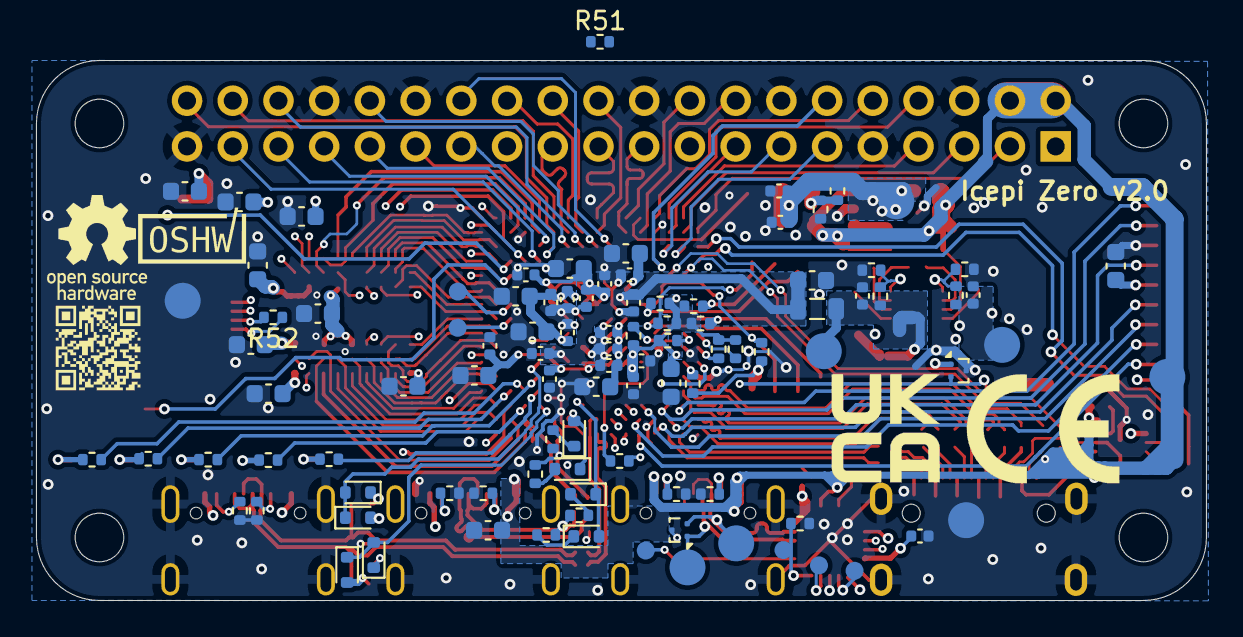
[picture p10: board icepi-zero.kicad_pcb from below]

Board: 4 copper layers, 65.0 x 30.0 mm, 170 parts (100 on the bottom side), 185 nets.

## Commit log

2026-01-02 Replaced memory AS4C16M16SA 54-TFBGA (8x8)
    [icepi-zero.kicad_pcb, sdram.kicad_sch]
2026-01-02 Removed LEDs D3, D4, D5
    [icepi-zero.kicad_pcb, icepi-zero.kicad_sch, sdram.kicad_sch]
2026-01-02 Added vias
    [icepi-zero.kicad_pcb]
2026-01-03 Connected traces to memory
    [icepi-zero.kicad_pcb]
2026-01-03 1.1V net capacitors
    [icepi-zero.kicad_pcb]
2026-01-03 2.5V LDO
    [icepi-zero.kicad_pcb]
2026-01-03 3.3V LDO
    [icepi-zero.kicad_pcb]
2026-01-03 3.3V memory fix
    [icepi-zero.kicad_pcb]
2026-01-03 HDMI preparation
    [icepi-zero.kicad_pcb]
2026-01-04 HDMI preparation, memory traces fix
    [icepi-zero.kicad_pcb]
2026-01-04 GND fix
    [icepi-zero.kicad_pcb]
2026-01-04 HDMI complete
    [icepi-zero.kicad_pcb]
2026-01-08 Initial plan for adding an external ADC
    [adc.kicad_sch, flash.kicad_sch, gpdi.kicad_sch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]
2026-01-08 ADC diff pair
    [icepi-zero.kicad_pcb]
2026-01-10 Minor changes
    [adc.kicad_sch, icepi-zero.kicad_pcb]
2026-01-12 Replaced 2.5 and 1.1V regulators with single LTC3407A-2
    [icepi-zero.kicad_pcb, power.kicad_sch]
2026-01-12 DRC fixes
    [icepi-zero.kicad_pcb]

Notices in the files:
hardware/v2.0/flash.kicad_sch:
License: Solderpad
